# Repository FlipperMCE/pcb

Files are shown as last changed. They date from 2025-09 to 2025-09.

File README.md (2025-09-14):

# FlipperMCE - PCB and Case

This repository contains the pcb files and the case for FlipperMCE - a GameCube Memory Card Emulator.

## PCB

Production files (gerbers/bom/cpl) for JLCPCB can be found in the releases section.

When ordering the PCB, make sure to use the following settings:

- 0.8 mm thickness
- ENIG finish

For the "connector" version, a display needs to be ordered separately.
Make sure, the display has a 0.5mm pitch with 30 Pins.
These displays can be found at aliexpress or other market places.

## Case

The case files are located in the ```case``` folder. For normal use, you would print:

- FlipperMCE_Bottom_v1.stl
- FlipperMCE_top_v1.stl
- FlipperMCE_Buttons_v1.stl
- either FlipperMCE_DisplayBracket_v1.stl or FlipperMCE_DisplayBracket_alter_v1.stl

Make sure to follow the assembly guide at [https://flippermce.github.io](https://flippermce.github.io) .

## Special Thanks

Special thanks goes to BitFunX (@gameBitfunx) for providing the pcb and case files for FlipperMCE <3!

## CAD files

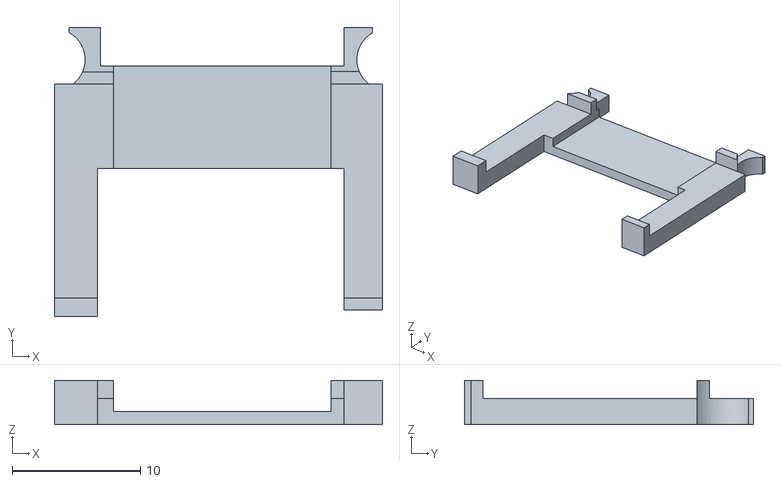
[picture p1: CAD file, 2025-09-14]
case/FlipperMCE_DisplayBracket_alter_v1.stl
25.6 x 22.5 x 3.47

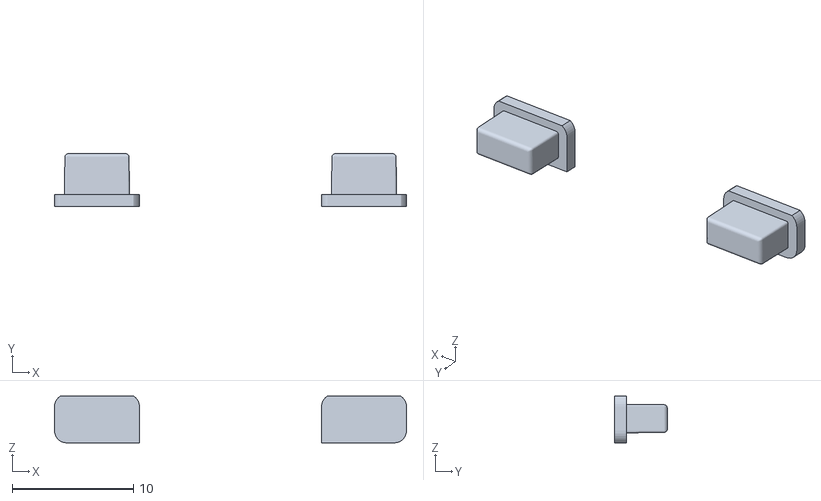
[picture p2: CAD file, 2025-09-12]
case/FlipperMCE_Buttons_v1.stl
29.0 x 4.35 x 3.85

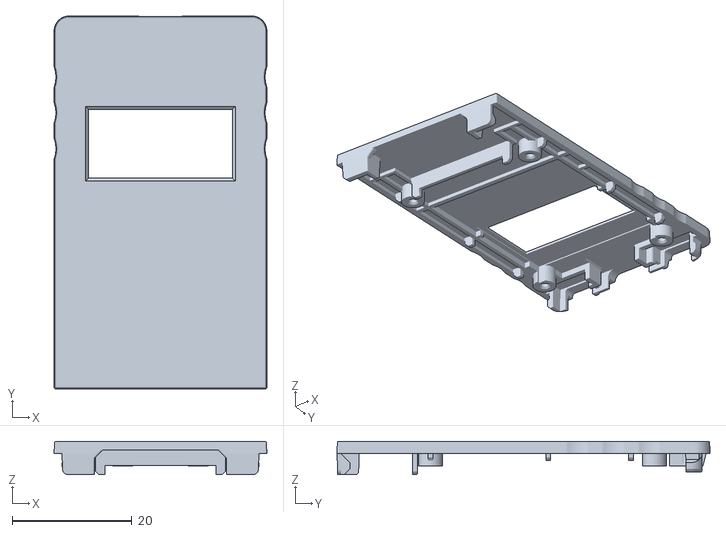
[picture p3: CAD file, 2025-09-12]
case/FlipperMCE_top_v1.stl
35.6 x 62.4 x 5.55

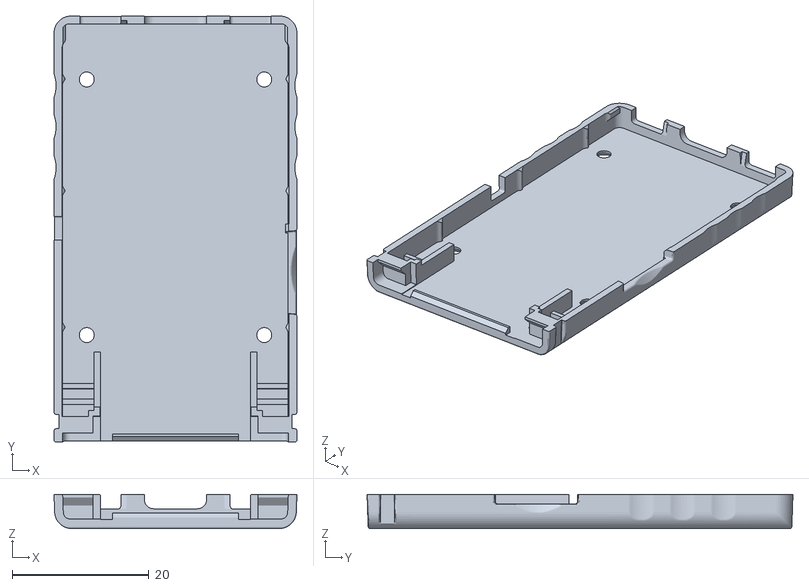
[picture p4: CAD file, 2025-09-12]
case/FlipperMCE_Bottom_v1.stl
35.6 x 62.4 x 5.00

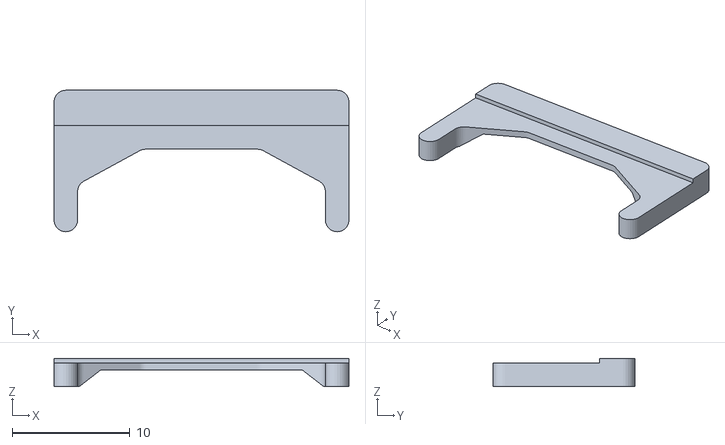
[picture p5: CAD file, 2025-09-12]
case/FlipperMCE_DisplayBracket_v1.stl
25.0 x 12.0 x 2.40

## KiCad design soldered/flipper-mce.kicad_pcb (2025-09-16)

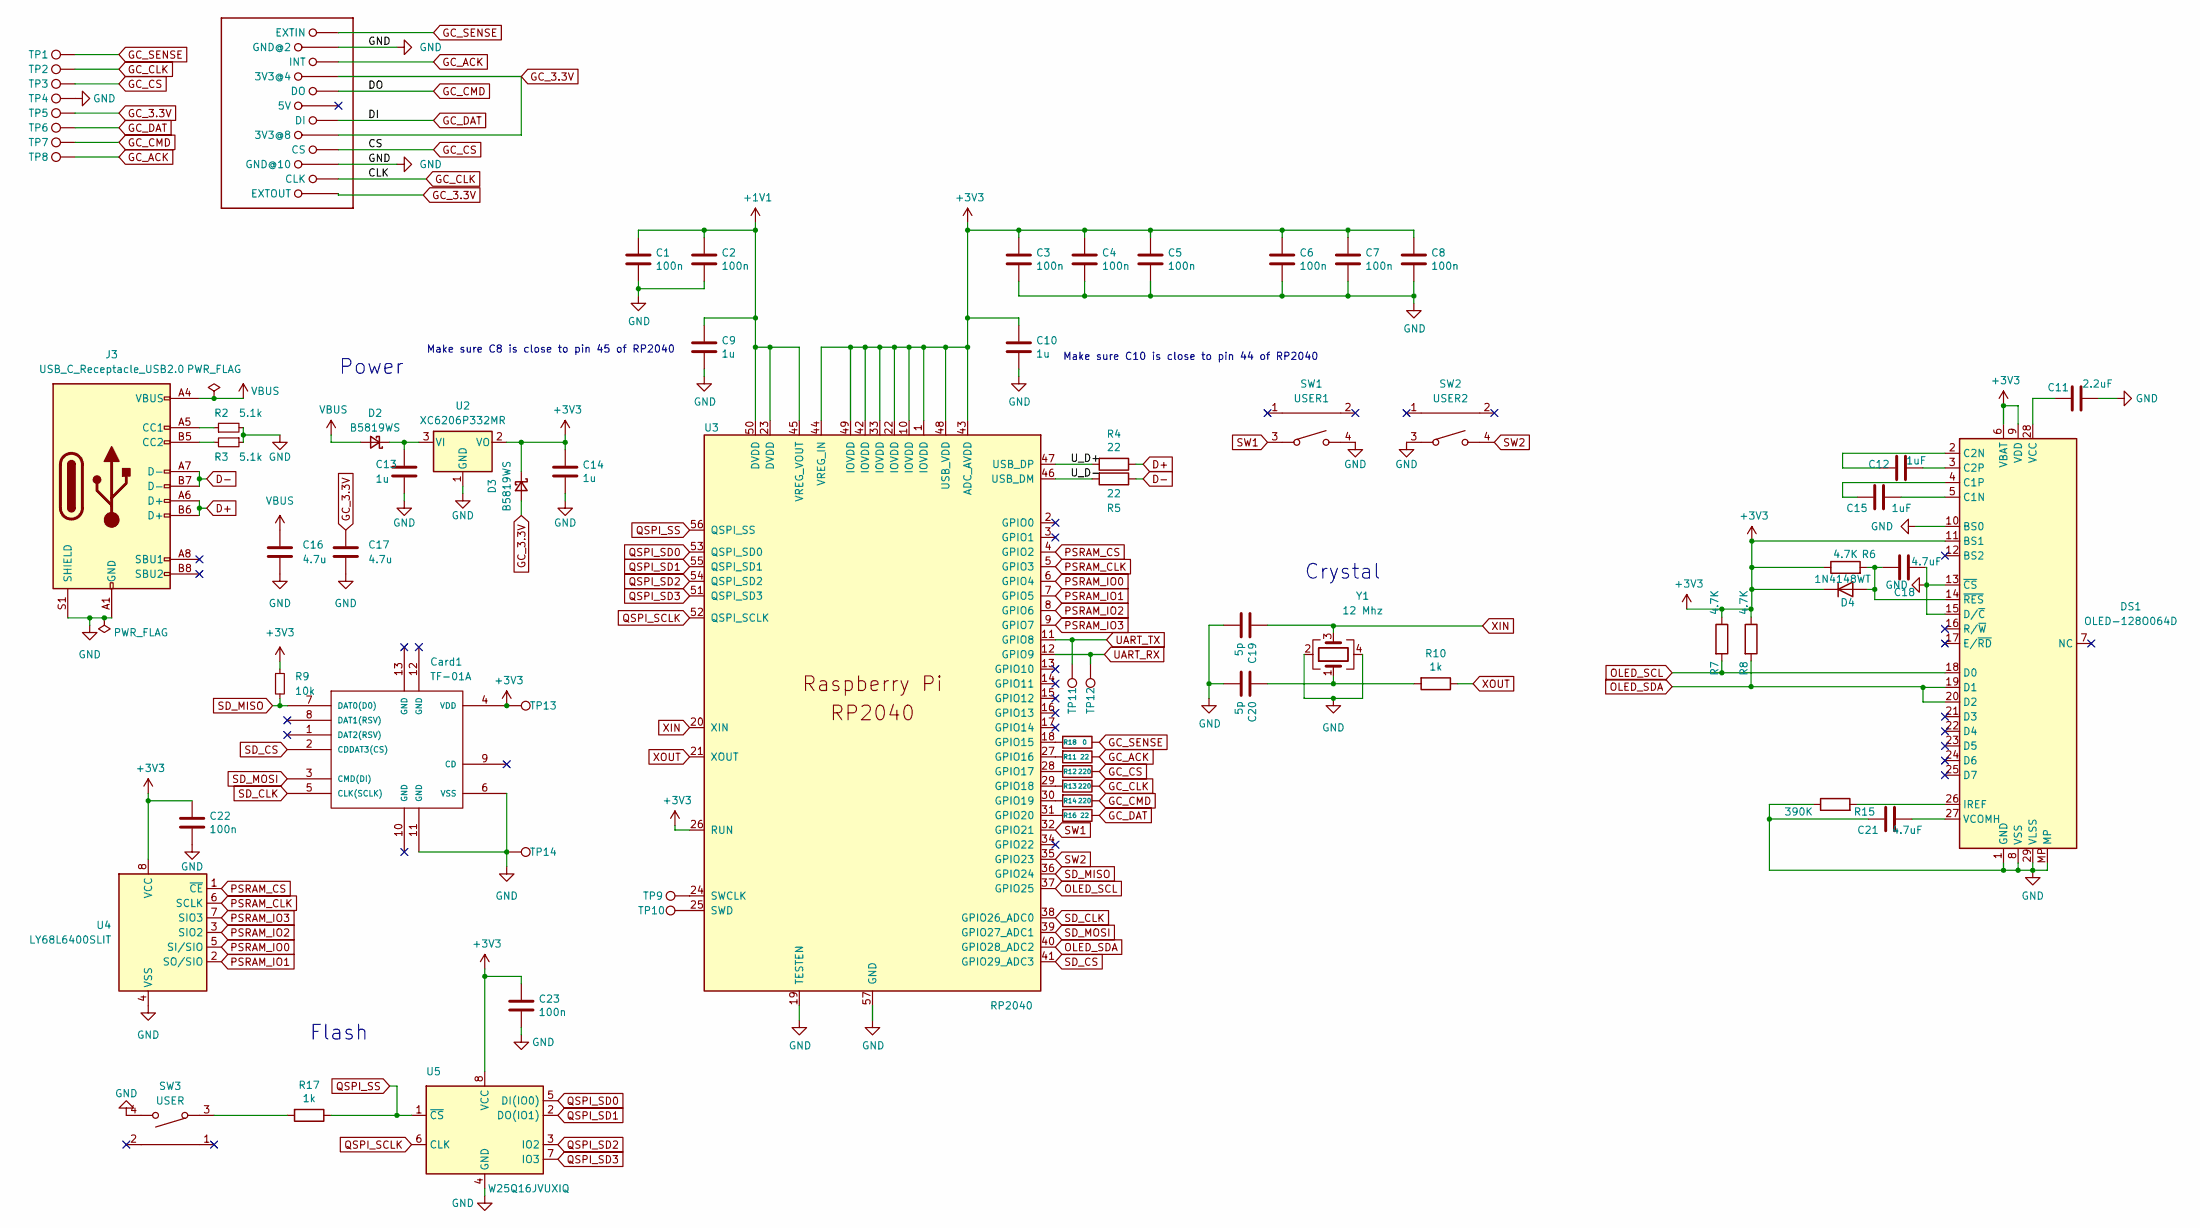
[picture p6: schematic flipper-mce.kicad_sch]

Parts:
C1, C2, C3, C4, C5, C6, C7, C8, C22, C23: 100n; C_0402_1005Metric; LCSC C1525
C9, C10, C13, C14: 1u; C_0402_1005Metric; LCSC C52923
C11: 2.2uF; C_0603_1608Metric
C12, C15: 1uF; C_0402_1005Metric
C16, C17: 4.7u; C_0603_1608Metric; LCSC C23733
C18, C21: 4.7uF; C_0603_1608Metric
C19, C20: 5p; C_0402_1005Metric; LCSC C1570
Card1: TF-01A; TF-SMD_TF-01A; LCSC C91145
D2, D3: B5819WS; D_SOD-323; LCSC C191023
D4: 1N4148WT; D_SOD-523
DS1: OLED-128O064D; GC_OLED_096
J2: GC_MEMCARD
J3: USB_C_Receptacle_USB2.0; USB_C_Receptacle_HRO_TYPE-C-31-M-12; LCSC C2765186
R2, R3: 5.1k; R_0402_1005Metric; LCSC C25905
R4, R5, R11, R16: 22; R_0402_1005Metric; LCSC C25092
R6, R7, R8: 4.7K; R_0402_1005Metric
R9: 10k; R_0402_1005Metric; LCSC C25744
R10, R17: 1k; R_0402_1005Metric; LCSC C11702
R12, R13, R14: 220; R_0402_1005Metric; LCSC C25091
R15: 390K; R_0402_1005Metric
R18: 0; R_0402_1005Metric; LCSC C25092
SW1: USER1; SW-SMD_TS24CA; LCSC C393942
SW2: USER2; SW-SMD_TS24CA; LCSC C393942
SW3: USER; SW-SMD_TS24CA; LCSC C393942
TP1, TP2, TP3, TP4, TP5, TP6, TP7, TP8, TP9, TP10, TP11, TP12, TP13, TP14: TestPoint; TestPoint_Pad_D1.0mm
U2: XC6206P332MR; SOT-23; LCSC C5446
U3: RP2040; RP2040-QFN-56; LCSC C2040
U4: LY68L6400SLIT; SOIC-8_3.9x4.9mm_P1.27mm; LCSC C261881
U5: W25Q16JVUXIQ; USON-8_2x3mm_P0.5mm; LCSC C97521
Y1: 12 Mhz; Crystal_SMD_3225-4Pin_3.2x2.5mm; LCSC C9002

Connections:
+1V1: C1.1, C2.1, C9.1, U3.23 (DVDD), U3.45 (VREG_VOUT), U3.50 (DVDD)
+3V3: C3.1, C4.1, C5.1, C6.1, C7.1, C8.1, C10.1, C14.1, C22.1, C23.1, Card1.4 (VDD), D3.1 (K), D4.1 (K), DS1.6 (VBAT), DS1.9 (VDD), DS1.11 (BS1), R6.1, R7.1, R8.1, R9.1, TP13.1, U2.2 (VO), U3.1 (IOVDD), U3.10 (IOVDD), U3.22 (IOVDD), U3.26 (RUN), U3.33 (IOVDD), U3.42 (IOVDD), U3.43 (ADC_AVDD), U3.44 (VREG_IN), U3.48 (USB_VDD), U3.49 (IOVDD), U4.8 (VCC), U5.8 (VCC)
/U_D+: R4.2, U3.47 (USB_DP)
/U_D-: R5.2, U3.46 (USB_DM)
D+: J3.A6 (D+), J3.B6 (D+), R4.1
D-: J3.A7 (D-), J3.B7 (D-), R5.1
GC_3.3V: C17.2, D3.2 (A), J2.4 (3V3@4), J2.8 (3V3@8), J2.12 (EXTOUT), TP5.1
GC_ACK: J2.3 (INT), R11.1, TP8.1
GC_CLK: J2.11 (CLK), R13.1, TP2.1
GC_CMD: J2.5 (DO), R14.1, TP7.1
GC_CS: J2.9 (CS), R12.1, TP3.1
GC_DAT: J2.7 (DI), R16.1, TP6.1
GC_SENSE: J2.1 (EXTIN), R18.1, TP1.1
GND: C1.2, C2.2, C3.2, C4.2, C5.2, C6.2, C7.2, C8.2, C9.2, C10.2, C11.2, C13.2, C14.2, C16.1, C17.1, C18.2, C19.2, C20.2, C21.1, C22.2, C23.2, Card1.6 (VSS), Card1.11 (GND), DS1.1 (GND), DS1.8 (VSS), DS1.10 (BS0), DS1.13 (~CS), DS1.15 (D/~C), DS1.29 (VLSS), DS1.30 (GND), DS1.MP, J2.2 (GND@2), J2.10 (GND@10), J3.A1 (GND), J3.A12 (GND), J3.B1 (GND), J3.B12 (GND), J3.S1 (SHIELD), R2.2, R3.1, R15.1, SW1.4, SW2.3, SW3.4, TP4.1, TP14.1, U2.1 (GND), U3.19 (TESTEN), U3.57 (GND), U4.4 (VSS), U5.4 (GND), Y1.2, Y1.4
unnamed: C20.1, R10.2, Y1.1
unnamed: C13.1, D2.1 (K), U2.3 (VI)
unnamed: C18.1, D4.2 (A), DS1.14 (~RES), R6.2
unnamed: C15.2, DS1.5 (C1N)
unnamed: C15.1, DS1.4 (C1P)
unnamed: C12.1, DS1.2 (C2N)
unnamed: C12.2, DS1.3 (C2P)
unnamed: DS1.26 (IREF), R15.2
unnamed: C11.1, DS1.28 (VCC)
unnamed: C21.2, DS1.27 (VCOMH)
unnamed: J3.A5 (CC1), R2.1
unnamed: J3.B5 (CC2), R3.2
unnamed: R17.2, SW3.3
unnamed: R18.2, U3.18 (GPIO15)
unnamed: R11.2, U3.27 (GPIO16)
unnamed: R12.2, U3.28 (GPIO17)
unnamed: R13.2, U3.29 (GPIO18)
unnamed: R14.2, U3.30 (GPIO19)
unnamed: R16.2, U3.31 (GPIO20)
unnamed: TP9.1, U3.24 (SWCLK)
unnamed: TP10.1, U3.25 (SWD)
OLED_SCL: DS1.18 (D0), R7.2, U3.37 (GPIO25)
OLED_SDA: DS1.19 (D1), DS1.20 (D2), R8.2, U3.40 (GPIO28_ADC2)
PSRAM_CLK: U3.5 (GPIO3), U4.6 (SCLK)
PSRAM_CS: U3.4 (GPIO2), U4.1 (~CE)
PSRAM_IO0: U3.6 (GPIO4), U4.5 (SI/SIO)
PSRAM_IO1: U3.7 (GPIO5), U4.2 (SO/SIO)
PSRAM_IO2: U3.8 (GPIO6), U4.3 (SIO2)
PSRAM_IO3: U3.9 (GPIO7), U4.7 (SIO3)
QSPI_SCLK: U3.52 (QSPI_SCLK), U5.6 (CLK)
QSPI_SD0: U3.53 (QSPI_SD0), U5.5 (DI(IO0))
QSPI_SD1: U3.55 (QSPI_SD1), U5.2 (DO(IO1))
QSPI_SD2: U3.54 (QSPI_SD2), U5.3 (IO2)
QSPI_SD3: U3.51 (QSPI_SD3), U5.7 (IO3)
QSPI_SS: R17.1, U3.56 (QSPI_SS), U5.1 (~CS)
SD_CLK: Card1.5 (CLK(SCLK)), U3.38 (GPIO26_ADC0)
SD_CS: Card1.2 (CDDAT3(CS)), U3.41 (GPIO29_ADC3)
SD_MISO: Card1.7 (DAT0(D0)), R9.2, U3.36 (GPIO24)
SD_MOSI: Card1.3 (CMD(DI)), U3.39 (GPIO27_ADC1)
SW1: SW1.3, U3.32 (GPIO21)
SW2: SW2.4, U3.35 (GPIO23)
UART_RX: TP12.1, U3.12 (GPIO9)
UART_TX: TP11.1, U3.11 (GPIO8)
VBUS: C16.2, D2.2 (A), J3.A4 (VBUS), J3.A9 (VBUS), J3.B4 (VBUS), J3.B9 (VBUS)
XIN: C19.1, U3.20 (XIN), Y1.3
XOUT: R10.1, U3.21 (XOUT)

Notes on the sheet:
Make sure C8 is close to pin 45 of RP2040
Flash
Crystal
Power
Make sure C10 is close to pin 44 of RP2040

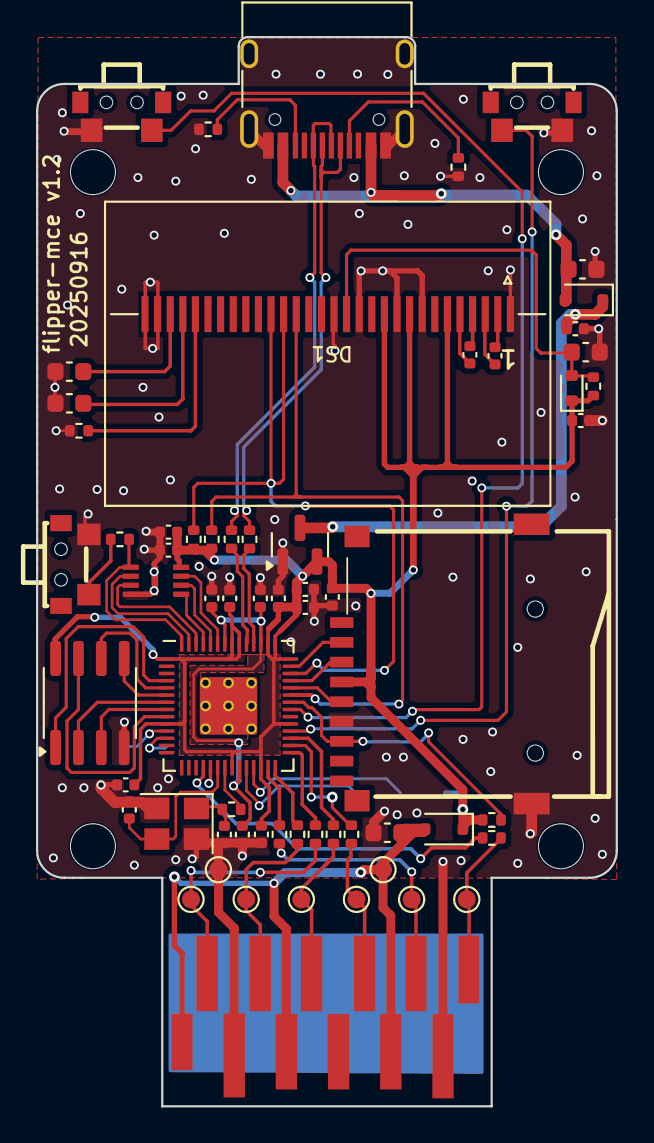
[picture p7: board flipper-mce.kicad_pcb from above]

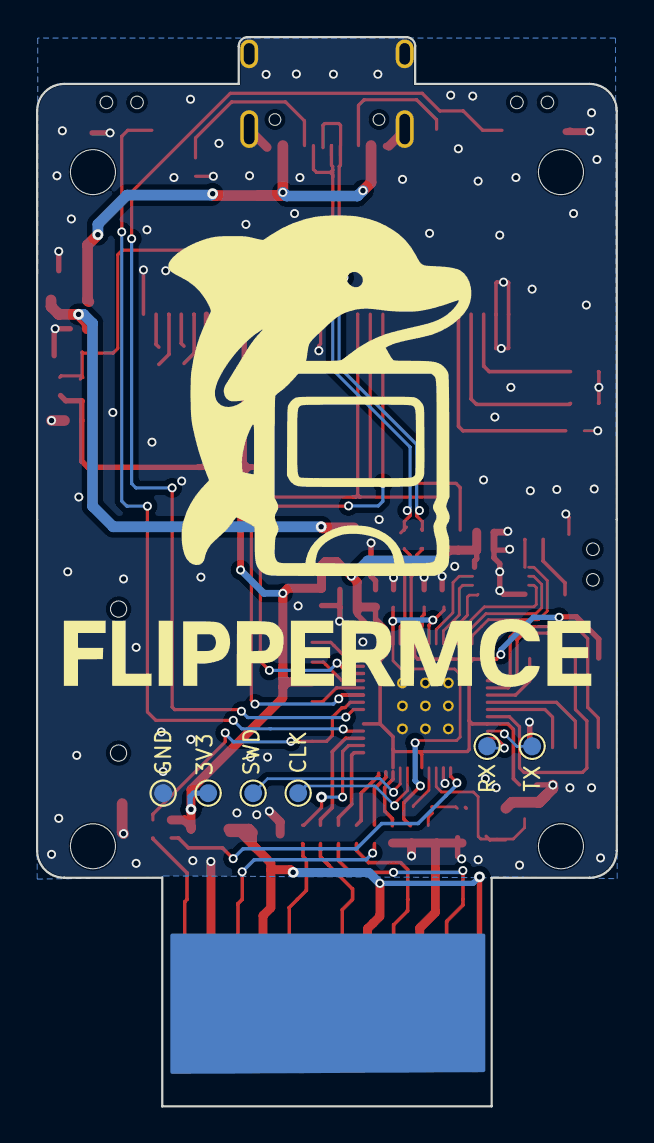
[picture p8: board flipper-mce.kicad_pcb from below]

Board: 2 copper layers, 32.2 x 59.4 mm, 69 parts (7 on the bottom side), 60 nets.

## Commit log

2025-09-12 Initial commit Case
    [FlipperMCE_Bottom_v1.stl, FlipperMCE_Buttons_v1.stl, FlipperMCE_DisplayBracket_v1.stl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]
2025-09-13 Fix Cap values
    [flipper-mce.kicad_sch]
2025-09-14 Alternative display bracket
    [FlipperMCE_DisplayBracket_alter_v1.stl]
2025-09-14 Add Case model stp
2025-09-16 Altered Layout for soldered OLED
    [BOM-flipper-mce.csv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]
2025-09-17 Fix BOM and CPL
    [BOM-flipper-mce.csv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]
2025-09-17 Remove production files for soldered
    [BOM-flipper-mce.csv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]
2025-09-24 Fix Connector
